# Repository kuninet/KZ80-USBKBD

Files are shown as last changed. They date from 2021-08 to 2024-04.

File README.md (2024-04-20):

# KZ80マイコン用 MSX USBキーボードアダプタ # 

## 概要 ##
* USBキーボードをRaspberry PI PICOにつなぎ、MSX互換のPPI(8255)へつなげるボードです。
  * HRA!氏のusb_keyboard_bridge_for_msxを使わせていただいています。

## 回路図

* [回路図(PDF)](https://github.com/kuninet/KZ80-USBKBD/blob/main/KiCAD/KZ80-USBKBD.pdf)

## 注意

* KiCADデータは [KiCAD](KiCAD)ディレクトリに入ってます。KiCad6を使用しています。KiCad v5以前では開けません。
* 基板製造データは[KiCAD/PCB](KiCAD/PCB)に入っています。
* ファームウェアの書き込みにはコツがいりますので、こちらのBLOG記事を参考にしてください。
  * [KZ80-USBKBD用 RaspberryPi Picoオブジェクトビルド方法](https://kuninet.org/2023/03/30/kz80-usbkbd%e7%94%a8-raspberrypi-pico%e3%82%aa%e3%83%96%e3%82%b8%e3%82%a7%e3%82%af%e3%83%88%e3%83%93%e3%83%ab%e3%83%89%e6%96%b9%e6%b3%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)

## ライセンスについて
* 私が作成した回路についてはMITライセンスで公開します。

## 参考・使用させていただいた情報
* usb_keyboard_bridge_for_msx
  * https://github.com/hra1129/msx_tools/tree/main/usb_keyboard_bridge_for_msx
* Raspberry Pi Pico シンボル&フットプリント
  * https://datasheets.raspberrypi.org/rp2040/VGA-KiCAD.zip

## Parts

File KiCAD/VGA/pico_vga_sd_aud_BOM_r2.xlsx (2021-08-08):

RPI-PVAS pico_vga_sd_aud BOM Rev2
17/079/2020
Reference designators | Quantity | Manufacturer Part Number (MPN) | Manufacturer | Description | Value
C1, C2 | 2 | GCM188R71C105KA64J | Murata | CAP CER 1UF 16V X7R 0603 | 1u
C9, C11 | 2 | GRM188R71A225KE15D | Murata | CAP CER 2.2UF 10V X7R 0603 | 2.2u
C3, C10, C16, C19 | 4 | GRM188R61A106KE69J | Murata | CAP CER 10UF 10V X5R 0603 | 10u
C4, C5, C6, C7, C8, C12, C13 | 7 | GRM155R71E104KE14J | Murata | CAP CER 0.1UF 25V X7R 0402 | 100n
C14, C15, C21 | 3 | GRM219R60J476ME44D | Murata | CAP CER 47UF 6.3V X5R 0805 | 47u
C17, C18 | 2 | GRM155R71H222KA01D | Murata | CAP CER 2200PF 50V X7R 0402 | 2.2n
D1 | 1 | MBR120VLSFT1G | ON Semiconductor | DIODE SCHOTTKY 20V 1A SOD123FL | MBR120VLSFT1G
J1, J2 | 2 | SJ-3523-SMT-TR | CUI Devices | CONN JACK STEREO 3.5MM SMD R/A | SJ-3523-SMT
J3 | 1 | 104031-0811 | Molex | CONN MICRO SD CARD PUSH-PULL R/A | 104031-0811
J4 | 1 | L77HDE15SD1CH4F | Amphenol ICC (Commercial Products) | CONN DSUB HD RCPT 15POS R/A SLDR | L77HDE15SD1CH4F
J5 | 1 | 10103594-0001LF | Amphenol ICC (FCI) | CONN RCPT USB2.0 MICRO B SMD R/A | 10103594-0001LF
J6 | 1 | TSW-102-23-T-S | Samtec Inc. | CONN HEADER VERT 2POS 2.54MM | TSW-102-23-T-S
J7 | 1 | 67997-208HLF | Amphenol ICC (FCI) | CONN HEADER VERT 8POS 2.54MM | 67997-208HLF
R1, R2 | 2 | RC0402FR-07220RL | Yageo | RES SMD 220 OHM 1% 1/16W 0402 | 220
R3, R4 | 2 | RC0402FR-07100RL | Yageo | RES SMD 100 OHM 1% 1/16W 0402 | 100
R5, R6 | 2 | RC0402FR-07470RP | Yageo | RES SMD 470 OHM 1% 1/16W 0402 | 470
R7, R8 | 2 | RC0402FR-071K8L | Yageo | RES SMD 1.8K OHM 1% 1/16W 0402 | 1.8K
R10, R11 | 2 | RC0402FR-0747RL | Yageo | RES SMD 47 OHM 1% 1/16W 0402 | 47
R20, R21, R22, R27, R32, R37 | 6 | RC0402FR-071KP | Yageo | RES SMD 1K OHM 1% 1/16W 0402 | 1k
R23, R24 | 2 | RC0402FR-0710KP | Yageo | RES SMD 10K OHM 1% 1/16W 0402 | 10k
R26, R31, R36 | 3 | RC0402FR-07499RL | Yageo | RES SMD 499 OHM 1% 1/16W 0402 | 499
R28, R33, R38 | 3 | RC0402FR-072KL | Yageo | RES SMD 2K OHM 1% 1/16W 0402 | 2k
R29, R34, R39 | 3 | RC0402FR-074K02L | Yageo | RES SMD 4.02K OHM 1% 1/16W 0402 | 4.02k
R30, R35, R40 | 3 | RC0402FR-078K06L | Yageo | RES SMD 8.06K OHM 1% 1/16W 0402 | 8.06k
SW1, SW2, SW3, SW4 | 4 | 434133025816 | Würth Elektronik | TACT SWITCH 4.2X3.2MM VERTICAL T | 434133025816
U1 | 1 | TLV70033DDCR | Texas Instruments | IC REG LINEAR 3.3V 200MA SOT23-5 | TLV70033DDCR
U3 | 1 | NC7WZ16P6X | ON Semiconductor | IC BUF NON-INVERT 5.5V SC70-6 | NC7WZ16P6X
U4 | 1 | PCM5101APWR | Texas Instruments | IC DAC 16/24/32BIT 384K 20TSSOP | PCM5101APWR

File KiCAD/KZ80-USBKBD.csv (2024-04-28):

Reference | Value | Qty |  | Footprint | Datasheet | DNP
C1 | 10u | 1 | 電解コンデンサ | Capacitor_THT:CP_Radial_D5.0mm_P2.50mm | ~
C2,C4,C5,C6 | 0.1u | 4 | 積層セラミックコンデンサ | Capacitor_THT:C_Disc_D3.0mm_W1.6mm_P2.50mm | ~
C3 | 0.022u | 1 | 積層セラミックコンデンサ | Capacitor_THT:C_Disc_D3.0mm_W1.6mm_P2.50mm | ~
D1 | KANA LED | 1 | 発光ダイオード | LED_THT:LED_D3.0mm | ~
D2 | CAPS LED | 1 | 発光ダイオード | LED_THT:LED_D3.0mm | ~
J1 | SBC8080 BUS | 1 | 2x20 40P ボックスヘッダ | Connector_PinHeader_2.54mm:PinHeader_2x20_P2.54mm_Horizontal | ~
J2 | CON-A | 1 | 2x7 14P ボックスヘッダ | Connector_PinHeader_2.54mm:PinHeader_2x07_P2.54mm_Vertical | ~
J3 | CMT-OUT | 1 | ステレオジャック | AJ-1780:AJ-1780
J4 | 232C(DEBUG) | 1 | 6P L型ピンヘッダ | Connector_PinHeader_2.54mm:PinHeader_1x06_P2.54mm_Horizontal | ~
J5 | ADR-JP2 | 1 | 2列x4 垂直ピンヘッダ | Connector_PinHeader_2.54mm:PinHeader_2x04_P2.54mm_Vertical | ~
J6 | ADR-JP1 | 1 | 2列x4 垂直ピンヘッダ | Connector_PinHeader_2.54mm:PinHeader_2x04_P2.54mm_Vertical | ~
JP1 | A7_JP | 1 | 1列x3 垂直ピンヘッダ | Connector_PinHeader_2.54mm:PinHeader_1x03_P2.54mm_Vertical | ~
R1,R2 | 1k | 2 | カーボン抵抗 | Resistor_THT:R_Axial_DIN0207_L6.3mm_D2.5mm_P10.16mm_Horizontal | ~
R3 | 4.7k | 1 | カーボン抵抗 | Resistor_THT:R_Axial_DIN0207_L6.3mm_D2.5mm_P10.16mm_Horizontal | ~
R4 | 47k | 1 | カーボン抵抗 | Resistor_THT:R_Axial_DIN0207_L6.3mm_D2.5mm_P10.16mm_Horizontal | ~
R5 | 100 | 1 | カーボン抵抗 | Resistor_THT:R_Axial_DIN0207_L6.3mm_D2.5mm_P10.16mm_Horizontal | ~
R6,R7,R8,R9 | 10k | 4 | カーボン抵抗 | Resistor_THT:R_Axial_DIN0207_L6.3mm_D2.5mm_P10.16mm_Horizontal | ~
RN1 | chB-PullUP | 1 | 集合抵抗器 10k | Resistor_THT:R_Array_SIP9 | http://www.vishay.com/docs/31509/csc.pdf
SW1 | SW_SPST | 1 | 基板実装 小型 SW | Connector_PinHeader_2.54mm:PinHeader_1x03_P2.54mm_Vertical | ~
U1 | Pico | 1 | Raspberry Pi Pico | RPi_Pico:RPi_Pico_SMD_TH
U2 | 8255 | 1 | i8255 パラレルIC | Package_DIP:DIP-40_W15.24mm_Socket | http://aturing.umcs.maine.edu/~meadow/courses/cos335/Intel8255A.pdf
U3 | 74HC139 | 1 | ロジックIC | Package_DIP:DIP-16_W7.62mm_Socket | http://www.ti.com/lit/gpn/sn74LS139
U4 | 74HC00 | 1 | ロジックIC | Package_DIP:DIP-14_W7.62mm_Socket | http://www.ti.com/lit/gpn/sn74hc00
MH1,MH2,MH3,MH4 | MountingHole | 4 | 基板穴 ※部品ではありません | MountingHole:MountingHole_3.2mm_M3 | ~

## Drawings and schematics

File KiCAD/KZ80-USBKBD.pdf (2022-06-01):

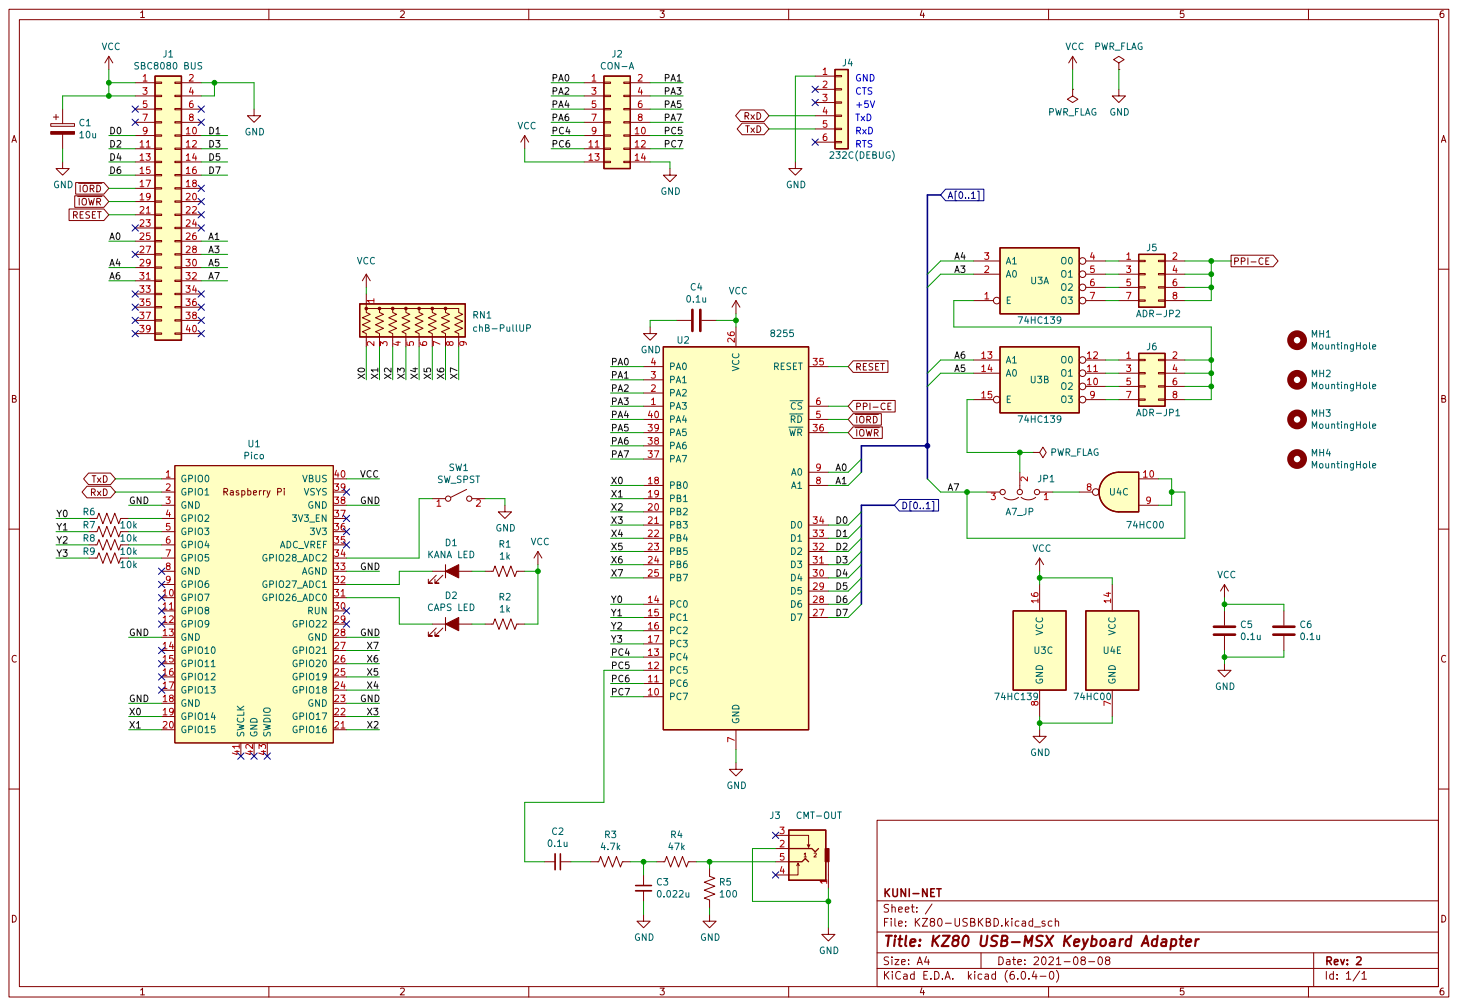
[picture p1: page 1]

File: KZ80-USBKBD.kicad_sch Sheet: / KUNI-NET C2

Id: 1/1 Title: KZ80 USB-MSX Keyboard Adapter

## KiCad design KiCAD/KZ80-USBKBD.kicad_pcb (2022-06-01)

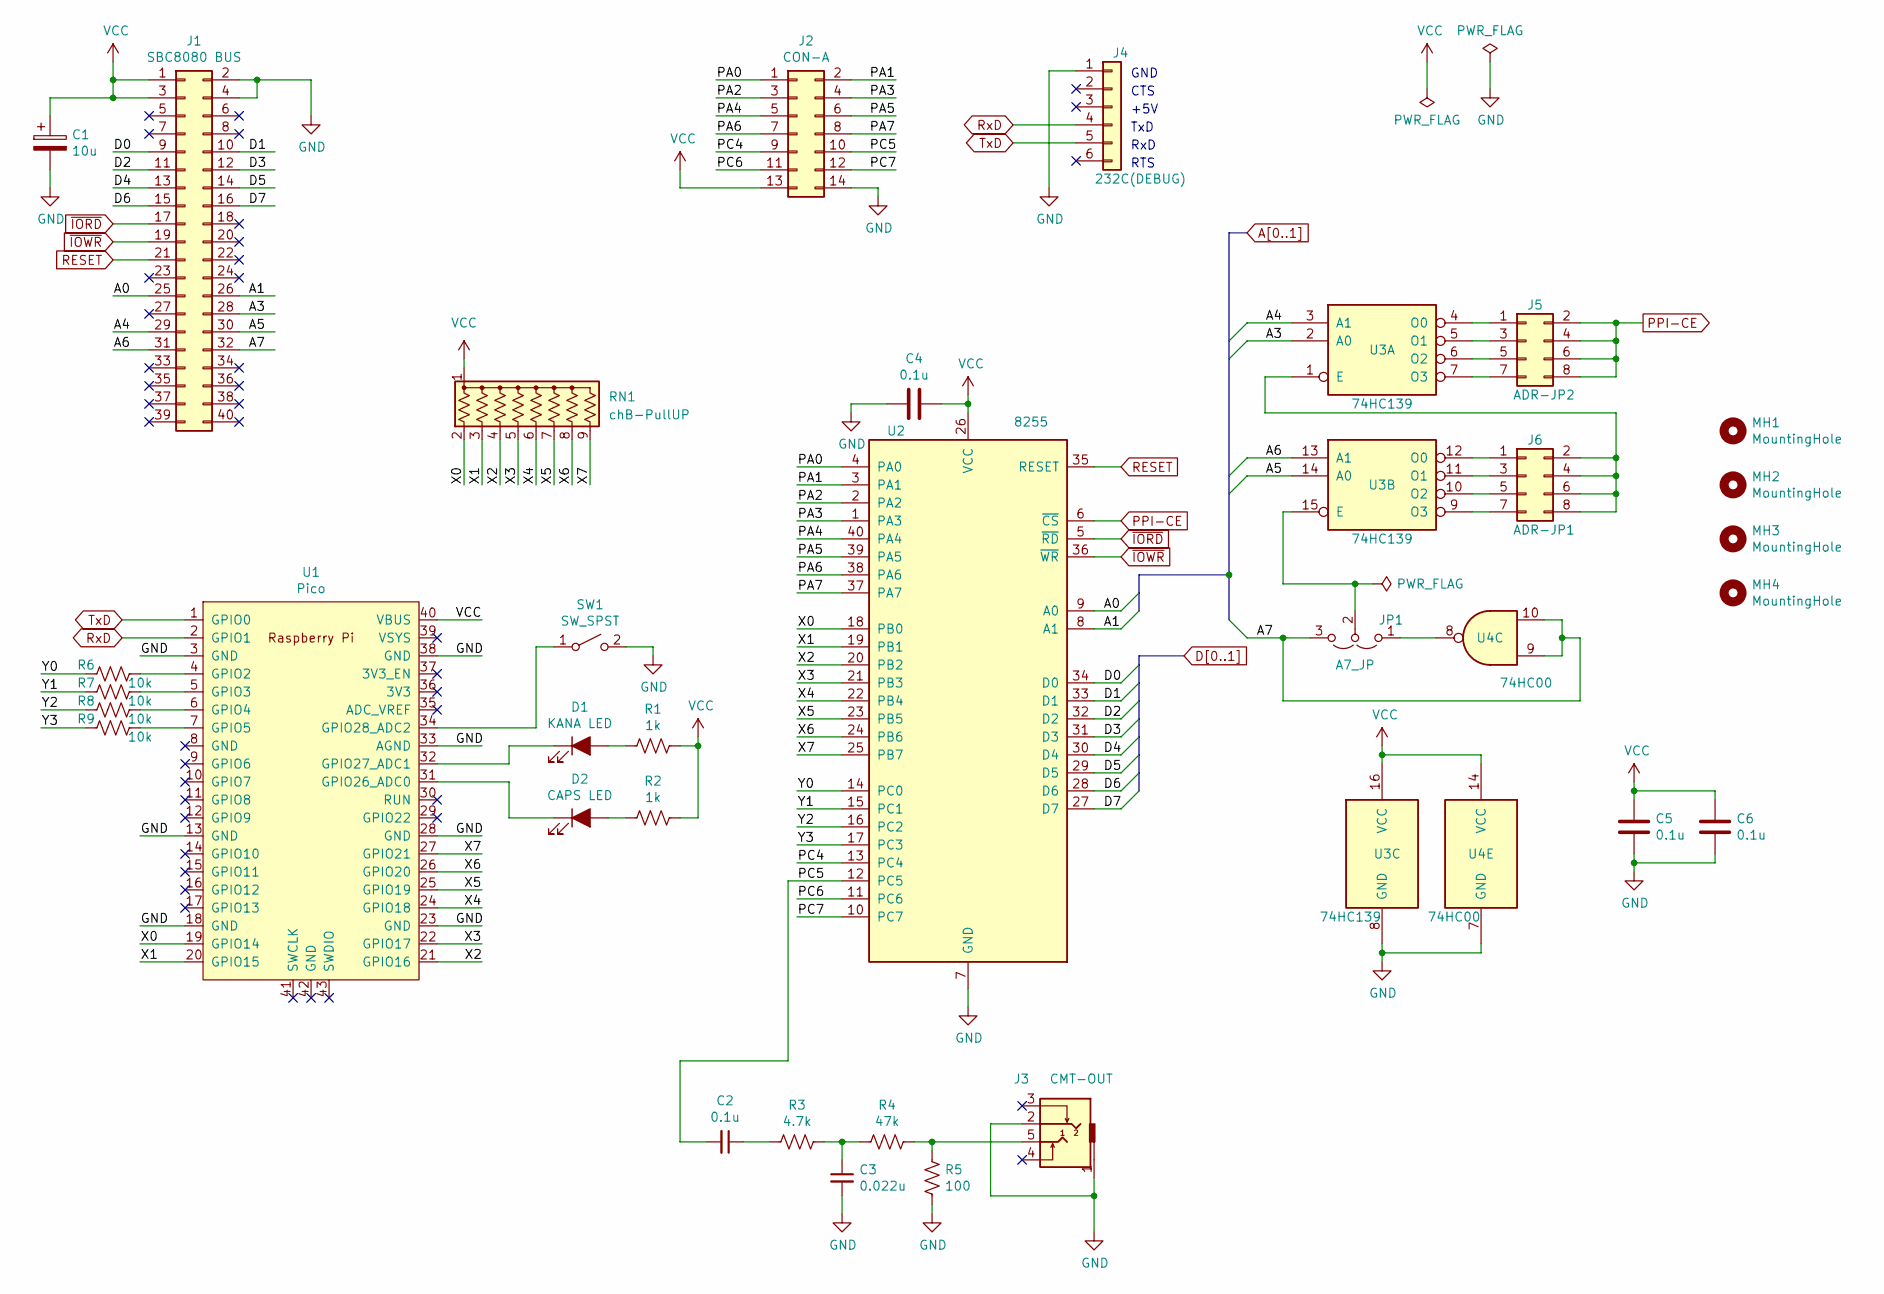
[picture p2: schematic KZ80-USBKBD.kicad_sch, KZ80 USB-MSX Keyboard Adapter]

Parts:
C1: 10u; CP_Radial_D5.0mm_P2.50mm
C2, C4, C5, C6: 0.1u; C_Disc_D3.0mm_W1.6mm_P2.50mm
C3: 0.022u; C_Disc_D3.0mm_W1.6mm_P2.50mm
D1: KANA LED; LED_D3.0mm
D2: CAPS LED; LED_D3.0mm
J1: SBC8080 BUS; PinHeader_2x20_P2.54mm_Horizontal
J2: CON-A; PinHeader_2x07_P2.54mm_Vertical
J3: CMT-OUT; AJ-1780
J4: 232C(DEBUG); PinHeader_1x06_P2.54mm_Horizontal
J5: ADR-JP2; PinHeader_2x04_P2.54mm_Vertical
J6: ADR-JP1; PinHeader_2x04_P2.54mm_Vertical
JP1: A7_JP; PinHeader_1x03_P2.54mm_Vertical
MH1, MH2, MH3, MH4: MountingHole; MountingHole_3.2mm_M3
R1, R2: 1k; R_Axial_DIN0207_L6.3mm_D2.5mm_P10.16mm_Horizontal
R3: 4.7k; R_Axial_DIN0207_L6.3mm_D2.5mm_P10.16mm_Horizontal
R4: 47k; R_Axial_DIN0207_L6.3mm_D2.5mm_P10.16mm_Horizontal
R5: 100; R_Axial_DIN0207_L6.3mm_D2.5mm_P10.16mm_Horizontal
R6, R7, R8, R9: 10k; R_Axial_DIN0207_L6.3mm_D2.5mm_P10.16mm_Horizontal
RN1: chB-PullUP; R_Array_SIP9
SW1: SW_SPST; PinHeader_1x03_P2.54mm_Vertical
U1: Pico; RPi_Pico_SMD_TH
U2: 8255; DIP-40_W15.24mm_Socket
U3: 74HC139
U4: 74HC00; DIP-14_W7.62mm_Socket

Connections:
/A3: J1.28, U3.2 (A0)
/A4: J1.29, U3.3 (A1)
/A5: J1.30, U3.14 (A0)
/A6: J1.31, U3.13 (A1)
/A7: J1.32, JP1.3 (B), U4.9, U4.10
/D2: J1.11, U2.32 (D2)
/D3: J1.12, U2.31 (D3)
/D4: J1.13, U2.30 (D4)
/D5: J1.14, U2.29 (D5)
/D6: J1.15, U2.28 (D6)
/D7: J1.16, U2.27 (D7)
/PA0: J2.1, U2.4 (PA0)
/PA1: J2.2, U2.3 (PA1)
/PA2: J2.3, U2.2 (PA2)
/PA3: J2.4, U2.1 (PA3)
/PA4: J2.5, U2.40 (PA4)
/PA5: J2.6, U2.39 (PA5)
/PA6: J2.7, U2.38 (PA6)
/PA7: J2.8, U2.37 (PA7)
/PC4: J2.9, U2.13 (PC4)
/PC5: C2.2, J2.10, U2.12 (PC5)
/PC6: J2.11, U2.11 (PC6)
/PC7: J2.12, U2.10 (PC7)
/X0: RN1.2 (R1), U1.19 (GPIO14), U2.18 (PB0)
/X1: RN1.3 (R2), U1.20 (GPIO15), U2.19 (PB1)
/X2: RN1.4 (R3), U1.21 (GPIO16), U2.20 (PB2)
/X3: RN1.5 (R4), U1.22 (GPIO17), U2.21 (PB3)
/X4: RN1.6 (R5), U1.24 (GPIO18), U2.22 (PB4)
/X5: RN1.7 (R6), U1.25 (GPIO19), U2.23 (PB5)
/X6: RN1.8 (R7), U1.26 (GPIO20), U2.24 (PB6)
/X7: RN1.9 (R8), U1.27 (GPIO21), U2.25 (PB7)
/Y0: R6.2, U2.14 (PC0)
/Y1: R7.2, U2.15 (PC1)
/Y2: R8.2, U2.16 (PC2)
/Y3: R9.2, U2.17 (PC3)
A0: J1.25, U2.9 (A0)
A1: J1.26, U2.8 (A1)
D0: J1.9, U2.34 (D0)
D1: J1.10, U2.33 (D1)
GND: C1.2, C3.2, C4.1, C5.2, C6.2, J1.2, J1.4, J2.14, J3.1, J3.2, J4.1, R5.2, SW1.2 (B), U1.3 (GND), U1.13 (GND), U1.18 (GND), U1.23 (GND), U1.28 (GND), U1.33 (AGND), U1.38 (GND), U2.7 (GND), U3.8 (GND), U4.7 (GND)
unnamed: C2.1, R3.2
unnamed: C3.1, R3.1, R4.2
unnamed: D1.1 (K), U1.32 (GPIO27_ADC1)
unnamed: D1.2 (A), R1.2
unnamed: D2.1 (K), U1.31 (GPIO26_ADC0)
unnamed: D2.2 (A), R2.2
unnamed: J3.5, R4.1, R5.1
unnamed: J5.1, U3.4 (O0)
unnamed: J5.3, U3.5 (O1)
unnamed: J5.5, U3.6 (O2)
unnamed: J5.7, U3.7 (O3)
unnamed: J6.1, U3.12 (O0)
unnamed: J6.2, J6.4, J6.6, J6.8, U3.1 (E)
unnamed: J6.3, U3.11 (O1)
unnamed: J6.5, U3.10 (O2)
unnamed: J6.7, U3.9 (O3)
unnamed: JP1.1 (A), U4.8
unnamed: JP1.2 (C), U3.15 (E)
unnamed: R6.1, U1.4 (GPIO2)
unnamed: R7.1, U1.5 (GPIO3)
unnamed: R8.1, U1.6 (GPIO4)
unnamed: R9.1, U1.7 (GPIO5)
unnamed: SW1.1 (A), U1.34 (GPIO28_ADC2)
PPI-CE: J5.2, J5.4, J5.6, J5.8, U2.6 (~CS)
RESET: J1.21, U2.35 (RESET)
RxD: J4.4, U1.2 (GPIO1)
TxD: J4.5, U1.1 (GPIO0)
VCC: C1.1, C4.2, C5.1, C6.1, J1.1, J1.3, J2.13, R1.1, R2.1, RN1.1 (common), U1.40 (VBUS), U2.26 (VCC), U3.16 (VCC), U4.14 (VCC)
~IORD: J1.17, U2.5 (~RD)
~IOWR: J1.19, U2.36 (~WR)

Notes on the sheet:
CTS
+5V
GND
RTS
RxD
TxD

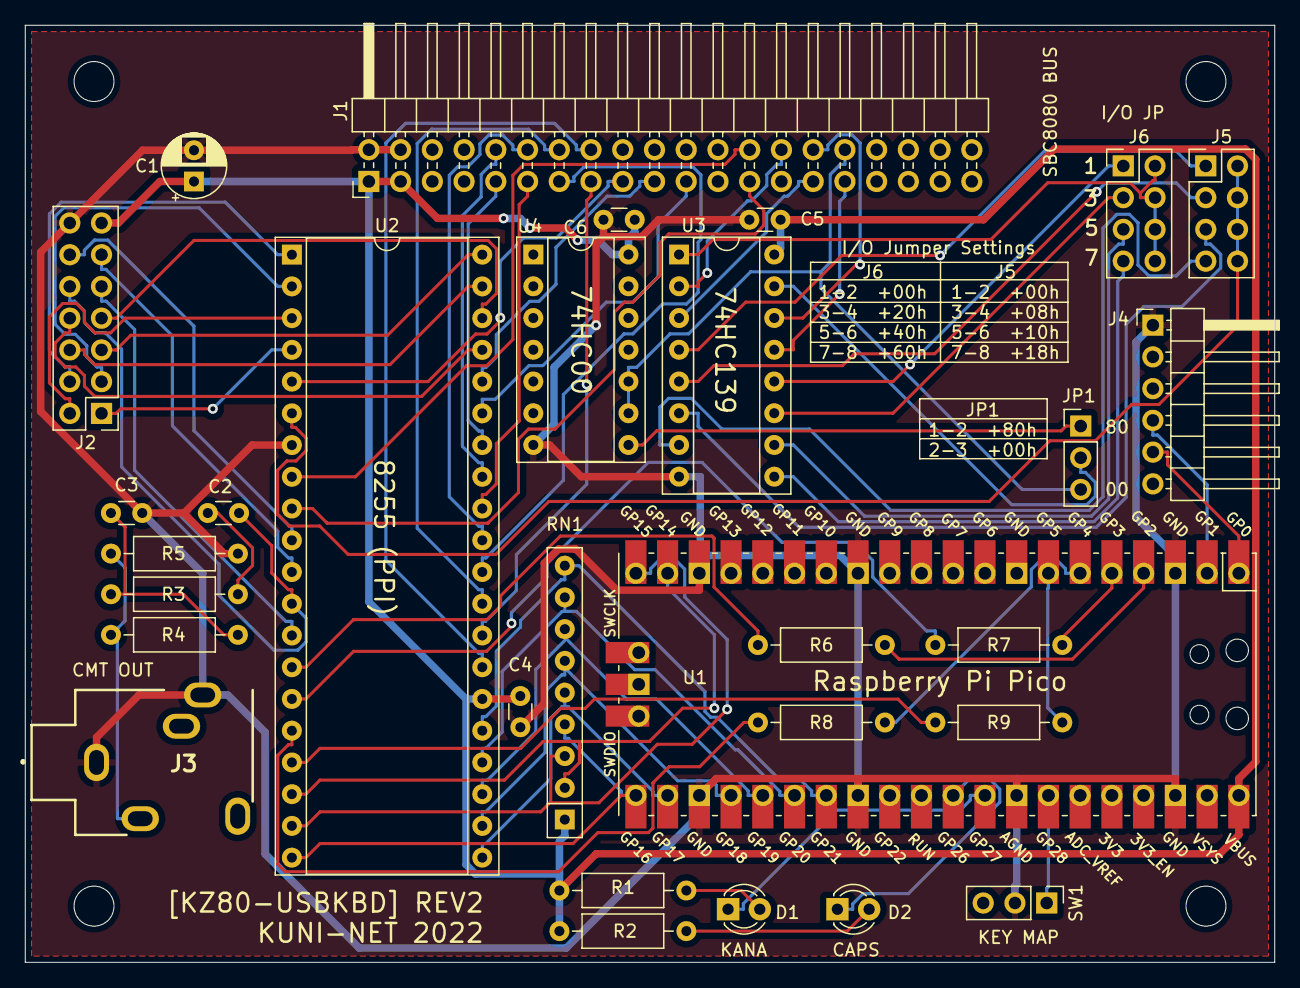
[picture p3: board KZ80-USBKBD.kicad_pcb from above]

Board: 2 copper layers, 100.0 x 75.0 mm, 34 parts (0 on the bottom side), 70 nets.

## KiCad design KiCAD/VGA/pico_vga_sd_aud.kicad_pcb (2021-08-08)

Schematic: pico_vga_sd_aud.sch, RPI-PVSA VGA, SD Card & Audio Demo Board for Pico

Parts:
C1, C2: 1u; C_0603_1608Metric
C3, C10, C16, C19: 10u; C_0603_1608Metric
C4, C5, C6, C7, C8, C12, C13: 100n; C_0402_1005Metric
C9, C11: 2.2u; C_0603_1608Metric
C14, C15, C21: 47u; C_0805_2012Metric
C17, C18: 2.2n; C_0402_1005Metric
D1: MBR120; MBR120_SOD-123
H1, H2, H3, H4: MountingHole; MountingHole_2.7mm_M2.5
J1, J2: AudioJack3; CUI_SJ-3523-audio-jack
J3: Micro_SD_Card; microSD_HC_Molex_104031-0811
J4: L77HDE15SD1CH4F; DSUB-15-L77HDE15SD1CH4F
J5: USB_B_Micro; USB_Micro-B_Amphenol_10103594-0001LF_Horizontal_modified
J6: Conn_01x02; PinHeader_1x02_P2.54mm_Vertical
J7: Conn_02x03_Odd_Even; PinHeader_2x04_P2.54mm_Vertical
R1, R2: 220; R_0402_1005Metric
R3, R4: 100; R_0402_1005Metric
R5, R6: 470; R_0402_1005Metric
R7, R8: 1.8K; R_0402_1005Metric
R9: DNF; R_0402_1005Metric
R10, R11: 47; R_0402_1005Metric
R20, R21, R22, R27, R32, R37: 1k; R_0402_1005Metric
R23, R24: 10k; R_0402_1005Metric
R26, R31, R36: 499; R_0402_1005Metric
R28, R33, R38: 2k; R_0402_1005Metric
R29, R34, R39: 4.02k; R_0402_1005Metric
R30, R35, R40: 8.06k; R_0402_1005Metric
SW1, SW2, SW3, SW4: SW_Push; SW_Push_1P1T_NO_Vertical_Wuerth_434133025816
U1: TLV70033_SOT23-5; SOT-23-5
U2: Pico; RPi_Pico_SMD_TH
U3: NC7WZ16P6X; SOT-363_SC-70-6
U4: PCM5101A; TSSOP-20_4.4x6.5mm_P0.65mm

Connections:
+5V: C21.2, D1.2, J5.1, J6.2
/GPIO0: R20.1, R30.2, U2.1 (GPIO0)
/GPIO1: R29.2, U2.2 (GPIO1)
/GPIO2: R28.2, U2.4 (GPIO2)
/GPIO3: R27.2, U2.5 (GPIO3)
/GPIO4: R26.2, U2.6 (GPIO4)
/GPIO5: J3.5, R9.2, U2.7 (GPIO5)
/GPIO6: R21.1, R35.2, U2.9 (GPIO6)
/GPIO7: R34.2, U2.10 (GPIO7)
/GPIO8: R33.2, U2.11 (GPIO8)
/GPIO9: R32.2, U2.12 (GPIO9)
/GPIO10: R31.2, U2.14 (GPIO10)
/GPIO11: R22.1, R40.2, U2.15 (GPIO11)
/GPIO12: R39.2, U2.16 (GPIO12)
/GPIO13: R38.2, U2.17 (GPIO13)
/GPIO14: R37.2, U2.19 (GPIO14)
/GPIO15: R36.2, U2.20 (GPIO15)
/GPIO16: R11.2, U2.21 (GPIO16)
/GPIO17: R10.2, U2.22 (GPIO17)
/GPIO18: J3.3, U2.24 (GPIO18)
/GPIO19: J3.7, U2.25 (GPIO19)
/GPIO20: J7.3, U2.26 (GPIO20)
/GPIO21: J7.1, U2.27 (GPIO21)
/GPIO22: J3.2, U2.29 (GPIO22)
/GPIO26: U2.31 (GPIO26_ADC0), U4.14
/GPIO27: U2.32 (GPIO27_ADC1), U3.3, U4.13
/GPIO28: U2.34 (GPIO28_ADC2), U3.1, U4.15
/HSYNC: J4.13, R11.1
/PCM_AUDIO_L: C18.1, J1.2, R5.1
/PCM_AUDIO_R: C17.1, J1.3, R6.1
/PCM_L: R5.2, U4.6
/PCM_R: R6.2, U4.7
/PWM_AUDIO_L: C14.1, J2.2, R7.2
/PWM_AUDIO_R: C15.1, J2.3, R8.2
/PWM_L: R1.2, U3.6
/PWM_LL: C7.1, C14.2, R1.1, R3.2
/PWM_R: R2.2, U3.4
/PWM_RR: C8.1, C15.2, R2.1, R4.2
/RUN: SW1.1, U2.30 (RUN)
/SD_DAT1: J3.8, J7.4, R24.1
/SD_DAT2: J3.1, J7.2, R23.1
/SWCLK: J7.6, U2.41 (SWCLK)
/SWDIO: J7.5, U2.43 (SWDIO)
/VGA_B: J4.3, R36.1, R37.1, R38.1, R39.1, R40.1
/VGA_G: J4.2, R31.1, R32.1, R33.1, R34.1, R35.1
/VGA_R: J4.1, R26.1, R27.1, R28.1, R29.1, R30.1
/VSYNC: J4.14, R10.1
/VSYS: C1.1, D1.1, U1.1, U1.3, U2.39 (VSYS)
GND: C1.2, C2.2, C3.2, C4.2, C5.2, C6.2, C7.2, C8.2, C9.2, C10.2, C12.2, C13.2, C16.2, C17.2, C18.2, C19.2, C21.1, J1.1, J2.1, J3.6, J3.11, J4.0, J4.5, J4.6, J4.7, J4.8, J4.10, J5.5, J5.6, J7.7, J7.8, R3.1, R4.1, R7.1, R8.1, R9.1, SW1.2, U1.2, U2.3 (GND), U2.8 (GND), U2.13 (GND), U2.18 (GND), U2.23 (GND), U2.28 (GND), U2.33 (AGND), U2.38 (GND), U2.42 (GND), U3.2, U4.3, U4.9, U4.10, U4.11, U4.12, U4.16, U4.19
unnamed: C9.1, U4.5
unnamed: C11.1, U4.2
unnamed: C11.2, U4.4
unnamed: C13.1, U4.18
unnamed: R20.2, SW2.2
unnamed: R21.2, SW3.2
unnamed: R22.2, SW4.2
VBUS: J6.1, U2.40 (VBUS)

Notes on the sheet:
Pico
Audio Power
I2S/PCM Audio
PWM Audio
Micro SD Card
VGA
Connect 5V to VBUS if Pico is using USB Host mode
5V Power In
Power Options: 1) Connect J5 to 5V uUSB power supply. This provides power for this board & Pico, via diode D1 to VSYS. 2) Connect uUSB power supply to Pico directly. VSYS will then power this board. N.B. If USB Host functionality is required on Pico, then use option 1, and also fit Jumper J6 to pro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
VGA 'DAC'
Button A
Button B
Button C
SD_CLK
SD_CMD
SD_DAT0
SD_DAT1
SD_DAT2
SD_DAT3
DIN
BCK_PWM1
LRCLK_PWM0
RED_0
RED_1
RED_2
RED_3
RED_4
GREEN_0
GREEN_1
GREEN_2
GREEN_3
GREEN_4
BLUE_0
BLUE_1
BLUE_2
BLUE_3
BLUE_4
UART1_TX
UART1_RX
UART / 4-bit SD Selector & Debug

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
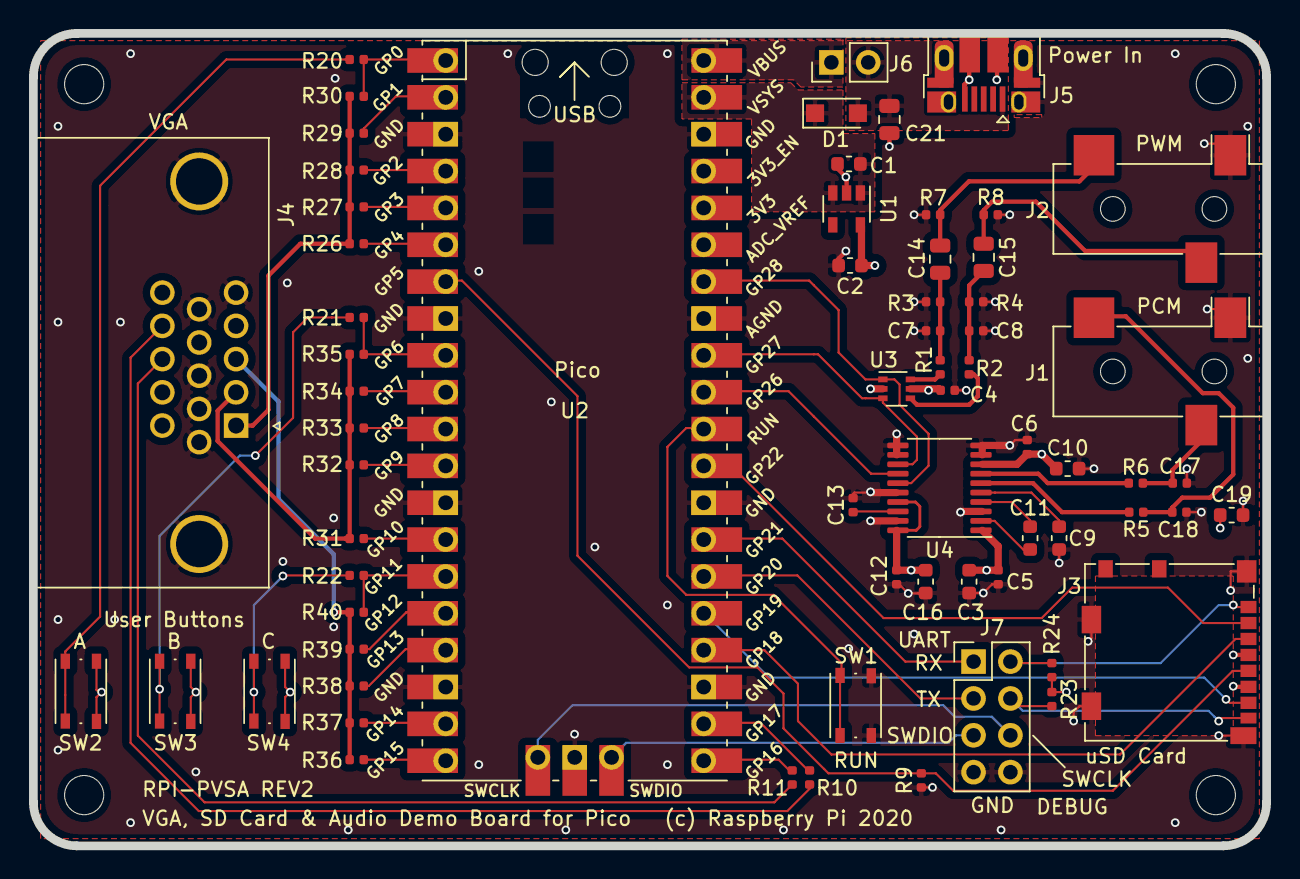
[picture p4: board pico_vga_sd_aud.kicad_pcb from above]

Board: 4 copper layers, 85.0 x 56.0 mm, 71 parts (0 on the bottom side), 59 nets.

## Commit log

2021-08-08 README 更新
2021-08-08 README更新 2
2021-08-08 基板製造ファイル移動
    [KZ80-USBKBD-B_Cu.gbl, KZ80-USBKBD-B_Mask.gbs, KZ80-USBKBD-B_Paste.gbp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]
2021-08-08 プリントパターン最新化
    [KZ80-USBKBD.kicad_pcb]
2021-08-08 ガーバーファイル整理
    [KZ80-USBKBD-B_Mask.gbs, KZ80-USBKBD-F_Mask.gts, KZ80-USBKBD-NPTH.drl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]
2021-08-08 LEDフットプリント間違い修正
    [KZ80-USBKBD.GBL, KZ80-USBKBD.GBO, KZ80-USBKBD.GBP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]
2021-08-08 回路図 PDF出力
2021-12-18 各種最新化
2022-01-17 REV1基板バグ対応、REV2作成、ガーバー出力
    [KZ80-USBKBD.GBL, KZ80-USBKBD.GBO, KZ80-USBKBD.GBP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]
2022-06-01 REV2 基板 回路不足部分追加・パターン修正・ガーバー再出力
    [KZ80-USBKBD.GBL, KZ80-USBKBD.GBO, KZ80-USBKBD.GBP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]
2024-04-28 部品表追加
    [KZ80-USBKBD.csv]
